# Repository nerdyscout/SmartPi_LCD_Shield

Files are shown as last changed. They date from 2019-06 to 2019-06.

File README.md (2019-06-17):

# SmartPi_LCD_Shield

Arduino LCD Shield fitting in top half of [DIN Rail Housing of CAMDENBOSS](https://www.camdenboss.com/camden-boss/cbrpi-dr-2-3-clr-pi-b%2c-p2%2c-p3-din-rail-enclosure/c-23/p-23019). A further adapter PCB is needed to connect to the RaspberryPi, see [SmartPi_IO_HAT](https://github.com/nerdyscout/SmartPi_IO_HAT).

But ofcourse this could be used directly with an Arduino as well.

Differnt assembly variants are available:
- LCDisplay and buttons via I2C port expander 
- LCDisplay via 4bit mode (only possible if RTC and RFM are not used!) and buttons on A1 
- RGB backlight of LCD supported 
- optional RTC with measurment of battery voltage at A0
- optional LORA RFM95 modul
- optional SDCard slot for data logging  
- optional buzzer (only via port expander)

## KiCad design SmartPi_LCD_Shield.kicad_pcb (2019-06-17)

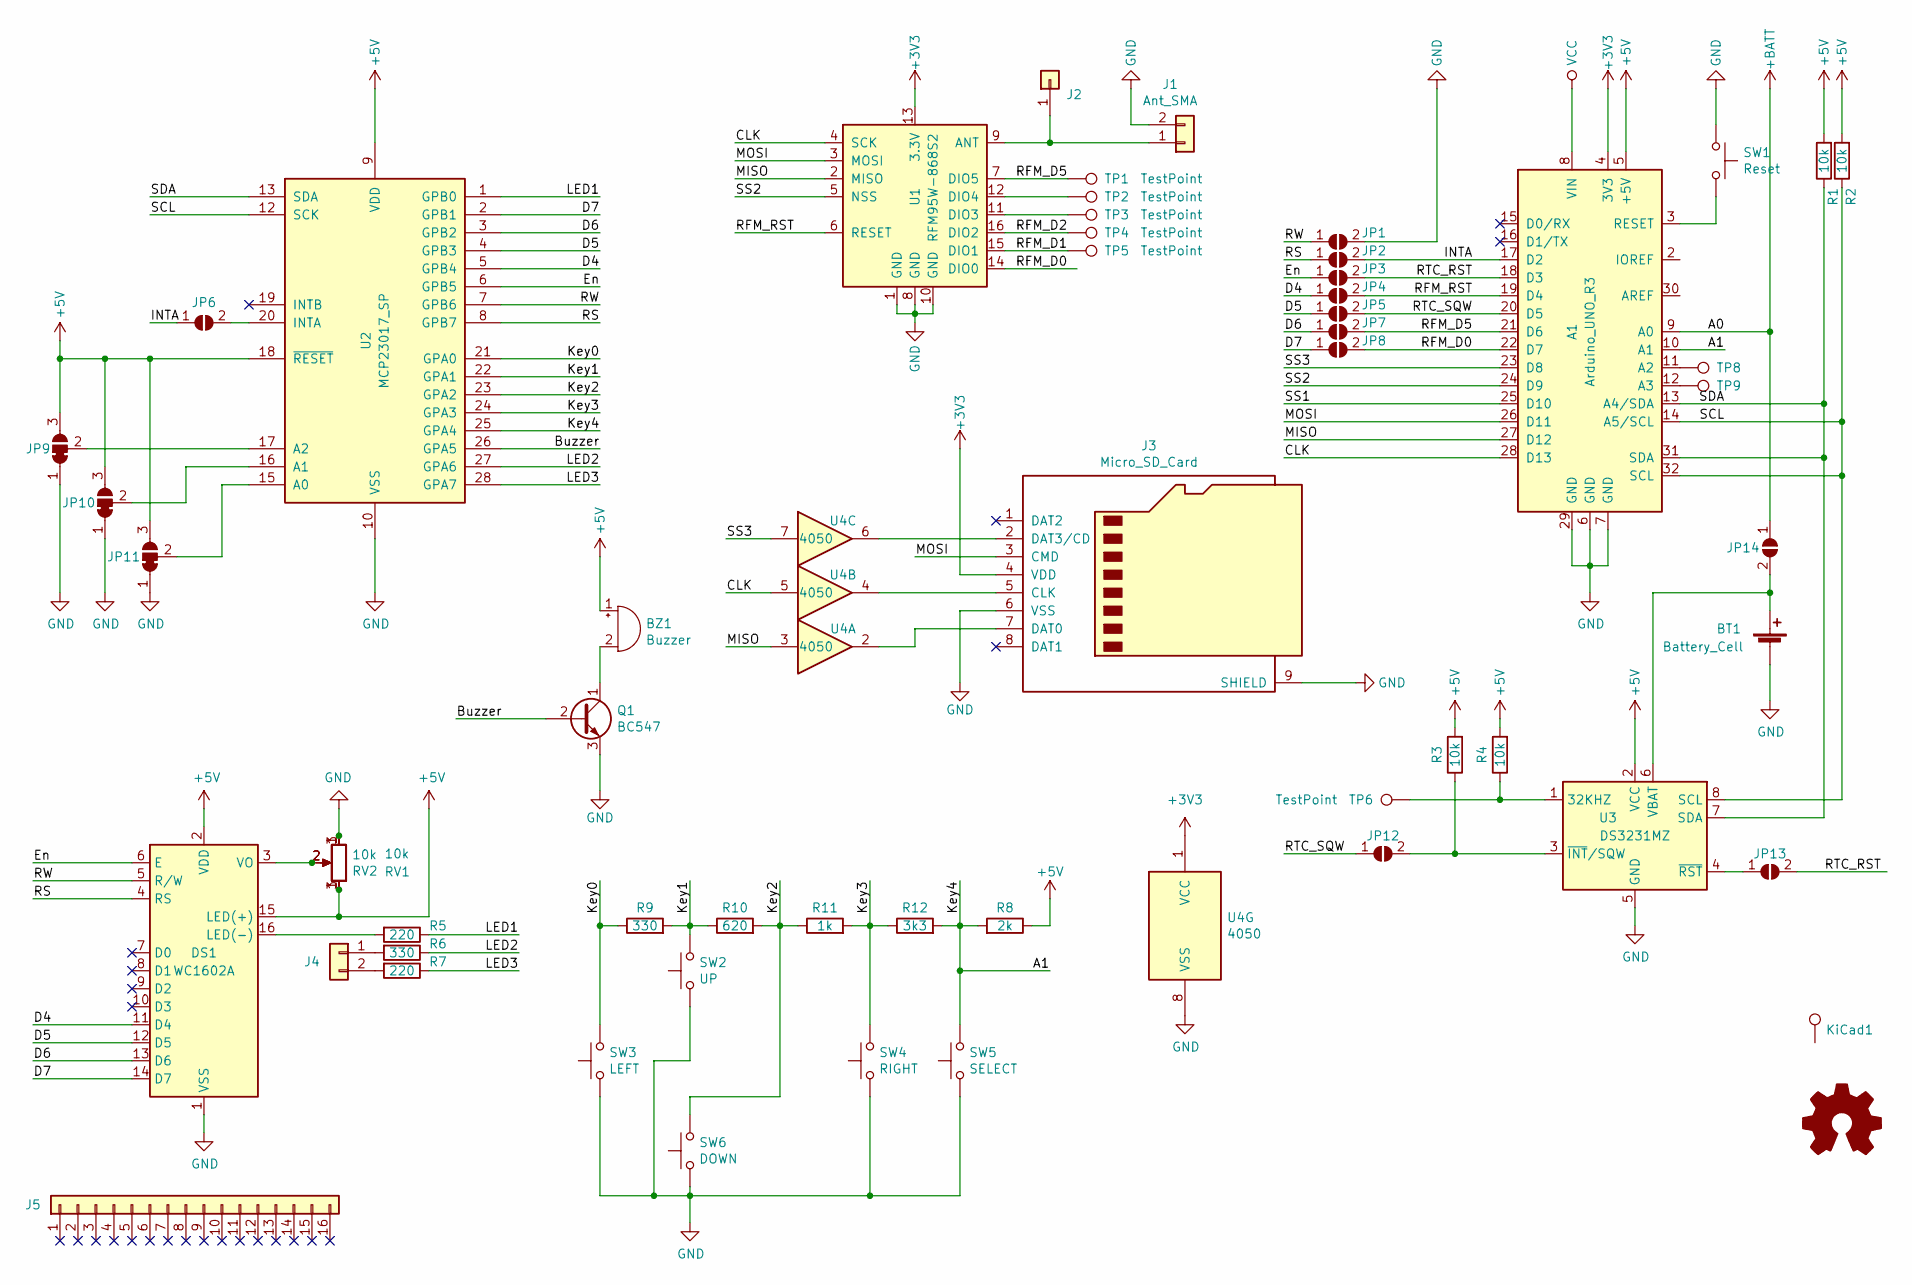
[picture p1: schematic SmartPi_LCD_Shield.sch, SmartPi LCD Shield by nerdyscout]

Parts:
A1: Arduino_UNO_R3
BT1: Battery_Cell; BatteryHolder_Keystone_3000_1x12mm
BZ1: Buzzer; MagneticBuzzer_Kingstate_KCG0601
DS1: WC1602A
J1: Ant_SMA; SMA_Amphenol_132289_EdgeMount
J2: Conn_01x01; PinSocket_1x01_P2.54mm_Vertical
J3: Micro_SD_Card; microSD_HC_Wuerth_693072010801
J4: Conn_01x02; PinHeader_1x02_P2.54mm_Vertical
J5: Conn_01x16; PinSocket_1x16_P2.54mm_Vertical
JP1, JP2, JP3, JP4, JP5, JP6, JP7, JP8, JP12, JP13, JP14: SolderJumper_2_Open; SolderJumper-2_P1.3mm_Open_RoundedPad1.0x1.5mm
JP9, JP10, JP11: SolderJumper_3_Bridged12; SolderJumper-3_P1.3mm_Bridged12_RoundedPad1.0x1.5mm_NumberL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
KiCad1: License; KiCad-Logo2_8mm_SilkScreen
LOGO1: Logo_Open_Hardware_Small; OSHW-Logo2_14.6x12mm_SilkScreen
Q1: BC547; TO-92_Inline
R1, R2, R3, R4: 10k; R_Axial_DIN0204_L3.6mm_D1.6mm_P7.62mm_Horizontal
R5, R7: 220; R_Axial_DIN0204_L3.6mm_D1.6mm_P7.62mm_Horizontal
R6, R9: 330; R_Axial_DIN0204_L3.6mm_D1.6mm_P7.62mm_Horizontal
R8: 2k; R_Axial_DIN0204_L3.6mm_D1.6mm_P7.62mm_Horizontal
R10: 620; R_Axial_DIN0204_L3.6mm_D1.6mm_P7.62mm_Horizontal
R11: 1k; R_Axial_DIN0204_L3.6mm_D1.6mm_P7.62mm_Horizontal
R12: 3k3; R_Axial_DIN0204_L3.6mm_D1.6mm_P7.62mm_Horizontal
RV1: 10k; Potentiometer_Bourns_3266P_Horizontal
RV2: 10k; Potentiometer_Bourns_3296X_Horizontal
SW1: Reset; SW_PUSH_6mm
SW2: UP; SW_PUSH_6mm
SW3: LEFT; SW_PUSH_6mm
SW4: RIGHT; SW_PUSH_6mm
SW5: SELECT; SW_PUSH_6mm
SW6: DOWN; SW_PUSH_6mm
TP1, TP2, TP3, TP4, TP5, TP6, TP8, TP9: TestPoint; TestPoint_Pad_D2.0mm
U1: RFM95W-868S2; HOPERF_RFM9XW_SMD
U2: MCP23017_SP; DIP-28_W7.62mm
U3: DS3231MZ; SOIC-8_3.9x4.9mm_P1.27mm
U4: 4050; SOIC-16_3.9x9.9mm_P1.27mm

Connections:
+3V3: A1.4 (3V3), J3.4 (VDD), U1.13 (3.3V), U4.1 (VCC)
+5V: A1.5 (+5V), BZ1.1 (-), DS1.2 (VDD), DS1.15 (LED(+)), JP9.3 (B), JP10.3 (B), JP11.3 (B), R1.2, R2.2, R3.2, R4.2, R8.1, RV1.1, RV2.3, U2.9 (VDD), U2.18 (~RESET~), U3.2 (VCC)
+BATT: A1.9 (A0), JP14.1 (A)
/A1: A1.10 (A1), R8.2, R12.2, SW5.2, U2.25 (GPA4)
/Buzzer: Q1.2 (B), U2.26 (GPA5)
/CLK: A1.28 (D13), U1.4 (SCK), U4.5
/D4: DS1.11 (D4), JP4.1 (A), U2.5 (GPB4)
/D5: DS1.12 (D5), JP5.1 (A), U2.4 (GPB3)
/D6: DS1.13 (D6), JP7.1 (A), U2.3 (GPB2)
/D7: DS1.14 (D7), JP8.1 (A), U2.2 (GPB1)
/En: DS1.6 (E), JP3.1 (A), U2.6 (GPB5)
/INTA: A1.17 (D2), JP2.2 (B), JP6.1 (A)
/Key0: R9.1, SW3.2, U2.21 (GPA0)
/Key1: R9.2, R10.1, SW2.2, U2.22 (GPA1)
/Key2: R10.2, R11.1, SW6.2, U2.23 (GPA2)
/Key3: R11.2, R12.1, SW4.2, U2.24 (GPA3)
/LED1: R5.1, U2.1 (GPB0)
/LED2: R6.1, U2.27 (GPA6)
/LED3: R7.1, U2.28 (GPA7)
/MISO: A1.27 (D12), U1.2 (MISO), U4.3
/MOSI: A1.26 (D11), J3.3 (CMD), U1.3 (MOSI)
/RFM_D0: A1.22 (D7), JP8.2 (B), U1.14 (DIO0)
/RFM_D1: TP5.1, U1.15 (DIO1)
/RFM_D2: TP4.1, U1.16 (DIO2)
/RFM_D5: A1.21 (D6), JP7.2 (B), TP1.1, U1.7 (DIO5)
/RFM_RST: A1.19 (D4), JP4.2 (B), U1.6 (RESET)
/RS: DS1.4 (RS), JP2.1 (A), U2.8 (GPB7)
/RTC_RST: A1.18 (D3), JP3.2 (B), JP13.2 (B)
/RTC_SQW: A1.20 (D5), JP5.2 (B), JP12.1 (A)
/RW: DS1.5 (R/W), JP1.1 (A), U2.7 (GPB6)
/SCL: A1.14 (A5/SCL), A1.32 (SCL), R2.1, U2.12 (SCK), U3.8 (SCL)
/SDA: A1.13 (A4/SDA), A1.31 (SDA), R1.1, U2.13 (SDA), U3.7 (SDA)
/SS2: A1.24 (D9), U1.5 (NSS)
/SS3: A1.23 (D8), U4.7
GND: A1.6 (GND), A1.7 (GND), A1.29 (GND), BT1.2 (-), DS1.1 (VSS), J1.2, J3.6 (VSS), J3.9 (SHIELD), JP1.2 (B), JP9.1 (A), JP10.1 (A), JP11.1 (A), Q1.3 (E), RV1.3, RV2.1, SW1.1, SW2.1, SW3.1, SW4.1, SW5.1, SW6.1, U1.1 (GND), U1.8 (GND), U1.10 (GND), U2.10 (VSS), U3.5 (GND), U4.8 (VSS)
unnamed: A1.3 (RESET), SW1.2
unnamed: A1.11 (A2), TP8.1
unnamed: A1.12 (A3), TP9.1
unnamed: BT1.1 (+), JP14.2 (B), U3.6 (VBAT)
unnamed: BZ1.2 (+), Q1.1 (C)
unnamed: DS1.3 (VO), RV1.2, RV2.2
unnamed: DS1.16 (LED(-)), R5.2
unnamed: J1.1, J2.1, U1.9 (ANT)
unnamed: J3.2 (DAT3/CD), U4.6
unnamed: J3.5 (CLK), U4.4
unnamed: J3.7 (DAT0), U4.2
unnamed: J4.1, R6.2
unnamed: J4.2, R7.2
unnamed: JP6.2 (B), U2.20 (INTA)
unnamed: JP9.2 (C), U2.17 (A2)
unnamed: JP10.2 (C), U2.16 (A1)
unnamed: JP11.2 (C), U2.15 (A0)
unnamed: JP12.2 (B), R3.1, U3.3 (~INT~/SQW)
unnamed: JP13.1 (A), U3.4 (~RST)
unnamed: R4.1, TP6.1, U3.1 (32KHZ)
unnamed: TP2.1, U1.12 (DIO4)
unnamed: TP3.1, U1.11 (DIO3)

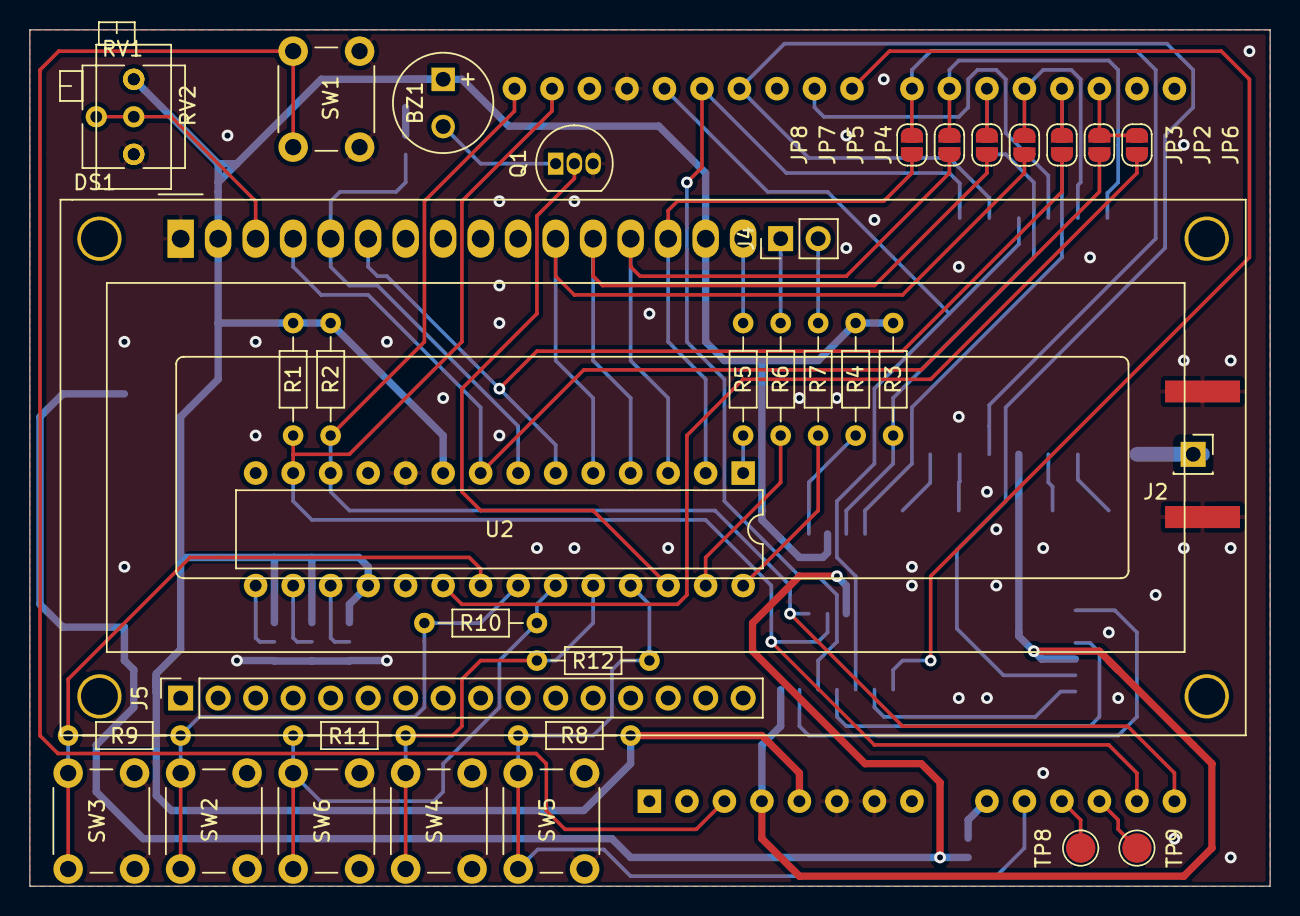
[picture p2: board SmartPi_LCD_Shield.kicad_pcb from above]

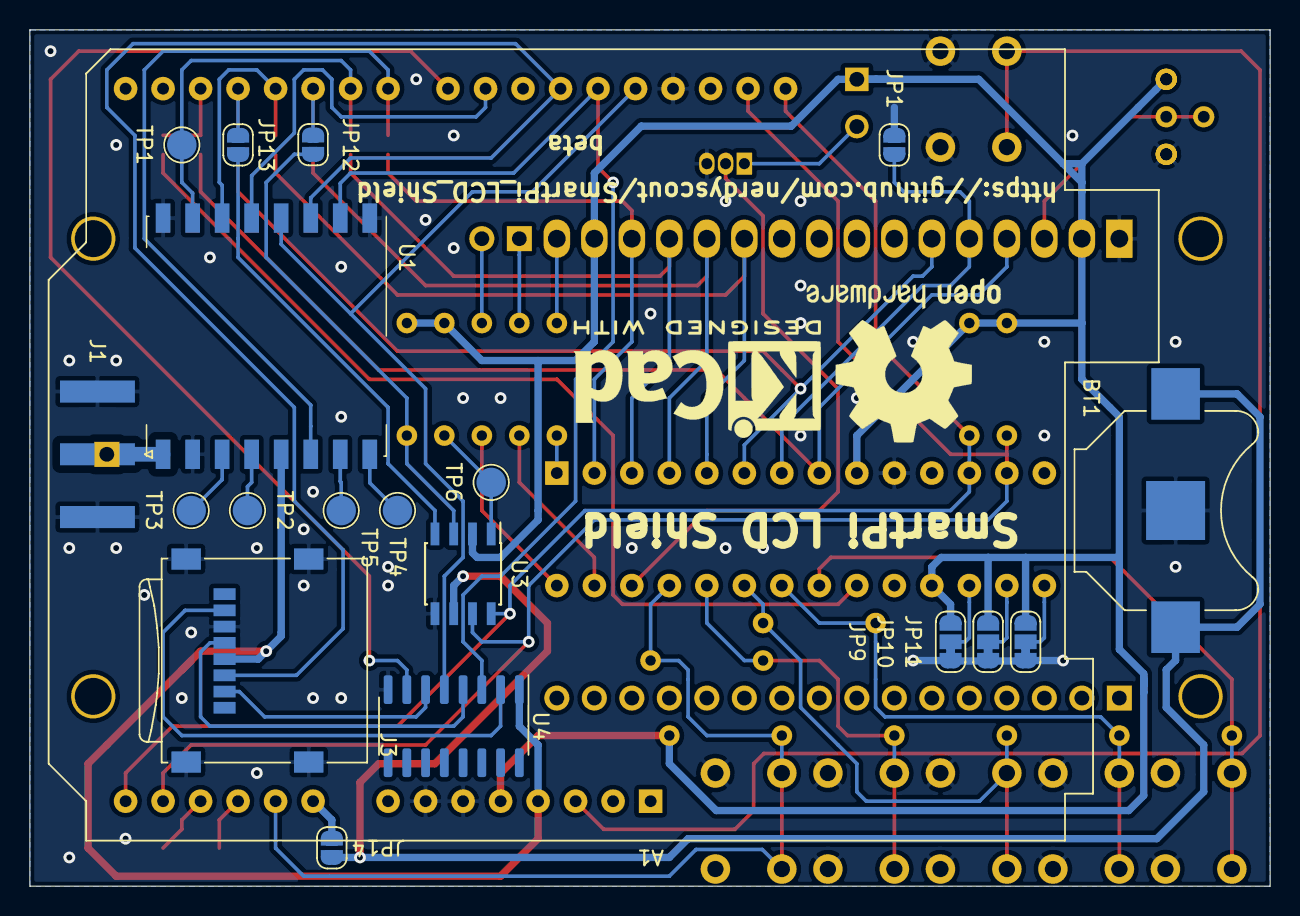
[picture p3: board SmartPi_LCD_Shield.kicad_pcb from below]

Board: 2 copper layers, 84.0 x 58.0 mm, 58 parts (22 on the bottom side), 57 nets.

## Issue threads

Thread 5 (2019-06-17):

write documentation

nerdyscout, 2019-06-17:
various pin of the expander have been swapped. create doc and example code how to use this PCB

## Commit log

2019-05-15 finished routing
    [SmartPi_LCD_Shield.kicad_pcb, SmartPi_LCD_Shield.sch]
2019-05-21 added hexbuffer for sd card
    [SmartPi_LCD_Shield.kicad_pcb, SmartPi_LCD_Shield.sch]
2019-05-24 routing complete with hex buffer
    [SmartPi_LCD_Shield.kicad_pcb, SmartPi_LCD_Shield.sch]
2019-06-17 added option for analog buttons
    [SmartPi_LCD_Shield.kicad_pcb, SmartPi_LCD_Shield.sch]
2019-06-17 new description
    [SmartPi_LCD_Shield.kicad_pcb, SmartPi_LCD_Shield.sch]
2019-06-17 page title
    [SmartPi_LCD_Shield.kicad_pcb, SmartPi_LCD_Shield.sch]
